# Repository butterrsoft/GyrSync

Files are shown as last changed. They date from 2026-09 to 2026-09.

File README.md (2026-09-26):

# 📺 GyrSync 

Gyr5

CRT TV/monitor protection and diagnostic dongle for 240p/15kHz, 25kHz and/or 480p/31kHz. With EDID, h-pos, v-pos, field-offset, and selectable sync pass/combine/polarity methods. Takes VGA/RGBHV input. Outputs C-sync on VGA pin 13 (or separate sync, if desired) when safe. Otherwise the Red led comes on and sync output is blocked. RGB still passes through, which is harmless on screen.

Powered via your VGA port, or any USB-C cable. Updates/reprograms via a single Gitbash Make command through an $8USD UPDI friend.

Gyrsync_x2

## Primary features
* Monitor sync protection at 15kHz and/or 25kHz and/or 31kHz.
* Vsync works at 45-65Hz input. But also when not present, so you can work only with H-sync if desired.
* Great for proving you're outputting the right video mode - comes in handy during system setup!
* VGA (TTL) RGBHV input only (Windows, Linux, MiSTer, HDMI-to-VGA) via DB15 3-row male plug, output via female socket.
* EDID can be turned on/off, and adjusted for H-size and H-pos. Or reprogrammed completely.
* H-pos, V-pos and field-offset direct adjustment.
* C-sync output with or without serration, separate H- and V-sync, sync polarity pass/flip.
* Three user profiles can hold different settings. 
* Lockout mode swallows stray button presses.
* Headless UI operation possible, for the most part.
* Diagnostic tools beyond the simple pass/fail sync rate indication, which itself is nothing to sneeze at!

Plan+test

### Read me first
Use a single power source wherever possible - try your VGA port first. If neither LED lights up, use a USB-C cable. *Don't* try to power other devices from the USB-C port on the Gyrsync. The Gyrsync has protection, but if something shorts you don't want to hurt anything.

There is one 1.27mm jumper inside the Gyrsync - allowing UPDI programming via VGA Pin 11 on the female VGA output side. This pin is no longer used by any display, but many/most cables tie it to ground. Leave the jumper off during normal use or the dongle mightn't boot if left in your setup (both red and green LED's will light dimly).

### Acknowledgments/Confessions:
I wanted to update Gambaman’s game-changing [Ultimate VGA to Scart Adapter](https://hackaday.io/project/165634-the-ultimate-vga-to-scart-adapter) and got carried away. Code by Claude, and, yes, I am embarrassed by that. All free and open-source, but who doesn't like seeing their name in print? 😆

## UI Navigation
UI is one button and one LED. Single button-presses change basic modes and adjust settings. Button-holds are timed to move between secondary modes, activating on release. Set the dongle as you want, then lock it so you can’t bump anything.

Dongle starts at Factory Reset – Mode 1, Profile 1, button locked out, Csync output, EDID off, all adjustments at default.

[Introduction and UI Navigation video](https://www.youtube.com/watch?v=2u9bSRtD6DU) Use the timestamps in the video if you need to. Keep the flowcharts below handy during use and remember that when holding the button down to move through the UI, the LED always gives some indication as you move to the next step.

UI full topology:
flowchart_Zeb_grey

UI simple topology:
```text
Lockout ──▶ Factory Reset
   │
   ▼
Modes 1-5 ──▶ Profile 1/2/3 ──▶ Mode S ──▶ Mode CS ──▶ Mode ED ──▶ Lockout ──▶ Factory Reset
                                    │
                                    ▼
                                 Mode H ──▶ Mode V ──▶ Mode FO
```

### Lockout Mode UI tables:
| Short press | No change |
|:---|:---|
| UI LED | Blinks mode, profile number |

| Hold, release | 3s | 10s |
|:---|:---|:---|
| UI LED | Blinking | Dark |
| Goes to | Mode 1-5, lockout removed | Factory reset |

### Mode 1-5 UI tables:
| Short press | Changes mode |
|:---|:---|
| UI LED | Blinks new mode, profile number |

| Hold, release | 2s | 4s | 6s | 8s | 11s | 13s | 16s | 25s |
|:---|:---|:---|:---|:---|:---|:---|:---|:---|
| UI LED | 1 blnk | 2 blnks | 3 blnks | 2+2 blnks | Solid | Dark | Blinking | Dark |
| Goes to | Profile 1 | Profile 2 | Profile 3 | Mode S | Mode CS | Mode ED | Lockout (at current settings) | Factory reset |

### Mode S UI tables:
| Short press | Goes to Mode 1 |
|:---|:---|
| UI LED | Blinks Mode 1, profile number |

| Double press | Toggle EDID on/off |
|:---|:---|
| UI LED | Accel./decel. pulses, respectively |

| Hold, release | 2s | 4s | 6s |
|:---|:---|:---|:---|
| UI LED | Solid | Dark | Blinking |
| Goes to | Mode H | Mode V | Mode FO |

### Adjustment Mode UI tables:
| Mode | H, V | ED, FO | CS |
|:---|:---|:---|:---|
| Short press | Step adj. | Step adj. | Sync pass/combine to next method |
| UI LED | Long blink middle and ends of adj. range only | Blink rate slower in middle, faster at ends. Long blink middle and ends. | Pulses method number |

| Hold | 2s | 4s | 6s | 8s (Mode ED only) |
|:---|:---|:---|:---|:---|
| UI LED | Solid | Dark | Solid | Pulsing |
| Action on release | Change adj. direction | Save adj. | Reset to default | Switch between pos/width (ED only) |

## Mode descriptions
Mode 1-5, Mode S information table:
| Mode |🔸Mode 1 | 🔸Mode 2 | 🔸Mode 3 | 🔸Mode 4 | 🔸Mode 5 | 🔸Mode S |
|:---|:---|:---|:---|:---|:---|:---|
| Passes | 15kHz | 31kHz | 15/31kHz | 25kHz | 15/25/31kHz | 15kHz + |
| EDID name | Mode1 - 15kHz | Mode 2 - 31kHz | Mode 3 - dualsyn | Mode 4 - 25kHz | Mode 5 - Trisync | Mode S - special |
| DTD 1 | 640x240p | 640x480p | 640x240p | 496x384p | 1280x240p | 640x240p |
| DTD 2 | 1280x240p | — | 1280x240p | — | 496x384p | 1280x240p |
| DTD 3 | 720x480i | — | 720x480i | — | 720x480i | 720x480i |

* DTD’s are timings/resolutions reported to Windows/Linux if you turn EDID on. Plug and play, baby! (In theory, at least, because Windows can be finicky and I'm waiting for more results from my testers. My RTX 5070, 980ti, old NV Quadro, and Radeon 5450's worked for 640x240p by simply plugging in the GyrSync after turning on EDID. My R7 360's do not.)
* Windows gets shitty about delivering interlaced video at low res in almost all cases.
* If your video mode pushes right up to the edges of any acceptable sync range, pass/fail detection is inconsistent and the output, along with your picture, will not be usable. Back off and move your modeline a notch or two inside the safe zone.
* Vsync (FPS) must be 45-65Hz, or absent entirely, or all output is blocked!

### 🔸 Mode S - special
Mode S passes 15kHz as normal, but takes 31kHz and halves it to make it 15kHz also - side-by-side images but at true 15kHz. This lets you use Safe Mode, or get out of trouble if Windows keeps grabbing 480p and pissing you off.

If there is no user activity, Mode S diagnoses sync status each 5s (but still blocks sync out of range). Will tell you if your cable is broken or wrong, or just that your system has gone to sleep.

Mode S sync report table:
| UI LED | 1 blink | 2 blinks | 3 blinks | Does nothing |
|:---|:---|:---|:---|:---|
| Means | No V-sync | No H-sync | No sync (both) | Sync ok |

### Adjustment modes
Adjustments are possible without a picture – power the dongle from any USB-C cable. The UI blinks SOS/cannot-adjust in only three scenarios: Mode FO if no interlaced mode is detected (progressive, or just missing vsync), Mode ED if EDID is off, Mode V if the source FPS is unstable. It is easiest to watch the screen while making most adjustments.

Adj. modes fall back to the mode you came from after 20s inactivity, or 30s for Mode ED. Same happens on reboot. Unsaved changes are discarded. After the long-blink at the end of an adjustment range, further presses move back in the other direction. The LED also long blinks at the default position.

Adj. mode h-sync pass table: (Prev. mode = if you were in Mode 4, 25kHz, then Mode ED is still at 25kHz.)
| Mode | Mode CS | Mode ED | Mode H | Mode V | Mode FO |
|:---|:---|:---|:---|:---|:---|
| Passes | Per prev. mode | Per prev. mode | 15/25/31kHz | 15/25/31kHz | 15/25/31kHz |

🔸 **Mode CS** - sync output method table: (On female DB15 output. Flip refers to the input sync polarity. Sync must be in range, still)
| Method | Mthd1 (default) | Mthd2 | Mthd3 | Mthd4 | Mthd5 | Mthd6 | Mthd7 |
|:---|:---|:---|:---|:---|:---|:---|:---|
| Pin13 (H-/C-sync)| Csync | Csync | Csync (no serr.) | pass | flip | pass | flip |
| Pin14 (V-sync)| block | pass | pass | pass | pass | flip | flip |

🔸 **Mode ED** - moves the h-pos and h-size in the EDID. Control defaults to h-pos/left, and when you hold for 8s goes to h-width/narrower. Changes affect *all* DTD’s over the current profile, across all modes. Different profiles can have different Mode ED settings. Changes do not show on the CRT as you make them - you must hit “Detect” under Windows Display Settings to see any changes, or, better, hot plug the dongle while USB-powered.

🔸 **Mode H** - moves h-pos. May *shimmy* very slightly, as the AVR32EB14 is only granular to 50ns. If you can, adjust the source, the CRT, or use Mode ED.

🔸 **Mode V** - moves v-pos.
 
🔸 **Mode FO** - field-offset! Interlaced only. Moves the odd field up and down vs the even field, to adjust flicker. I really wanted to try this, and it works, though YMMV.

## EDID
Extended Display Identification Data. Your OS reads it from any monitor and then sends the video timing mode the monitor asked for. The GyrSync transmits 15kHz, 25kHz and 31kHz timings based on how you set it. Modern OS’s are finicky, won’t do interlaced, but *should* grab the base 240p mode from the 15kHz timings and simply display it. Or 384p/480p depending on what you set. Wait for the green LED on the Gyrsync before plugging in your CRT.

**Troubleshooting EDID**
* [Go into Mode S](https://www.youtube.com/watch?v=2u9bSRtD6DU&t=462s) and [turn on EDID](https://www.youtube.com/watch?v=2u9bSRtD6DU&t=543s)
* Windows Display Settings > Advanced Display Settings for Desktop Resolution vs Active Signal Resolution. [Turn off scaling in your GPU settings](https://www.youtube.com/watch?v=IokpZT4ZYq4)
* Some older GPU's, OSes, or HDMI-to-VGA adapters may need a monitor plugged in, but not necessarily turned on, for the GyrSync to be detected. 
* Some HDMI-to-VGA dongles may mux-in EDID, which is ok, or simply provide their own, which is not.
* The EDID's allow audio over HDMI - change sound output in Windows if you need to.
* Something like crt_emudriver, CRU, or setting a cmdline.txt EDID in Linux, can override any physical EDID, and you won't see the GyrSync or it’s modelines listed anywhere. (Sync-protection and other features will still work as normal)

HDMI-to-VGA adapters can be great, but most cheap ones are now complete shit. At time of writing, [this cheap one](https://www.aliexpress.com/item/32976152001.html?spm=a2g0o.order_list.order_list_main.30.49cd1802Jc2KAH) works with the GyrSync, and probably with 240p in general :) (You need the flat cable version with audio). To use this particular converter you need a monitor plugged in, as above.

## Reprogramming:
The GyrSync targets an AVR32EB14, and is intended to be a simple as possible to reprogram. On Windows it needs [ZakKemble's latest AVR build](https://github.com/ZakKemble/avr-gcc-build) along with the install exe's, not zips, for [Git](https://git-scm.com/install/windows) and [Make](https://gnuwin32.sourceforge.net/packages/make.htm). Install git and make, then copy `make.exe`, `libintl3.dll` and `libiconv2.dll` into C:\Program Files\Git\usr\bin (or wherever you installed) or set your paths.

Programming is via UPDI 3-wire serial protocol. Unplug from your GPU or VGA source. Get a low-voltage UPDI friend/clone from aliexpress. Or even cheaper a USB-to-serial adapter set up as this:

UPDI

On the Gyrsync, stick pins into the VGA female end – pin 9 is 5V, pin 6, 7 or 8 for GND, and pin 11 for UPDI. Remember the 1.27mm UPDI jumper, or bridge the pins in a reversible fashion. Then open a gitbash (in any right-click context-menu) where you have the project files and type `make clean` then `make TOOLDIR="C:/path/to/avr-gcc-16.1.0-x64-windows/bin/" AVRDUDE="C:/path/to/avr-gcc-16.1.0-x64-windows/bin/avrdude.exe" flash PORT=COM6` remembering to check those paths and com port.

Most USB-to-serial adapters should work, like a CP2102, or even those CH341 eeprom programmers like below (just flip the jumper to TTL and use the pins as marked on the reverse). I did have trouble with a CH340-based cable though.

CH341

I wish i could have used USB or something, but the price and size goes up, and microcrontrollers with CCL and/xor gates don't use USB :/

### Editing EDID files (for programming)
Edit the project EDID files using a free program like Deltacast, or substitute your own EDID's, but keep the project filenames. The build needs all 6 EDID files named the same as the originals, at either 128 or 256 bytes. The intent is to allow you to adjust the picture a bit or add your own DTD timings, monitor names, etc. There is no protection from bad EDID files in the code, though it will still allow/block sync ranges as normal. If you do not add a CEA extension block or pad the EDID, the code will add an extension block making HDMI audio possible. If you get into trouble, restore the original EDID's.

Linux needs separate EDID's as it interprets the interlaced descriptor differently. 480i on Windows = 240i@60Hz, on Linux = 480i@30Hz. If you don't use interlaced modes you won't notice.

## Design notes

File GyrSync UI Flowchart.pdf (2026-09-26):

Red LED lit means no valid sync present, or another issue. Nothing passed. Green LED lit means valid sync present and video being passed
Blue LED blinks to indicate status, as detailed below
Time in seconds(s) refer to button press-hold time required; # = number in context

STATUS (report): # long blinks = MODE #, then # short blinks = PROFILE # (e.g. 1 long blink +2 short = Mode 1, PROFILE 2) ▲
│
│<3s | 10s
LOCKOUT | ───▶ RESET dark
│ | (Factory settings)
│3s
▼
MODE | 2s | 1 blink | 8s | 2+2 blinks | 11s solid | 13s dark
SELECT | ───▶ PROFILE #1 ───▶ MODE S | ───────────▶ | MODE CS
* | ───────▶ MODE ED

*
│ | │ | │ | (sync) | │ | (EDID adjust)
│ | │4s | 2 blinks | | │<2s | Reports | 16s blinking
│ | ───▶ PROFILE #2 | │ | STATUS | ───────▶ LOCKOUT
│ | │ | ─────▶ | sets MODE 1 | │ | (saves settings)
│ | │6s | 3 blinks | | │ | | 25s dark
│ | ───▶ PROFILE #3 | │<2s x 2 | Accelerating pulses = on | ───────▶ RESET
│ | │ | Decelerating pulses = off | (Factory settings)
│ | | | | ─────▶ | EDID ON / OFF
│ | | | | │ | (toggle)
│ | | | | │2s
│ | | | | ─────▶ | MODE H
*
(H-pos adjust)
│ | | | | │
│<2s | | | | │4s
▼ | | | | ─────▶ | MODE V

*
(V-pos adjust)
MODE +1, modes cycle 1-5, then | │
Reports STATUS (see above) | │6s
Refer Mode Descriptions below | ─────▶ | MODE FO*
(Field Offset)

* Refer Adjustment Mode UI Tables below for more information
Please watch videos: GyrSync - 15kHz/31kHz CRT protection dongle - Introduction & UI overview (https://www.youtube.com/watch?v=2u9bSRtD6DU) GyrSync - Win 10 EDID process - Active Signal Resolution vs Desktop Resolution. (https://www.youtube.com/watch?v=IokpZT4ZYq4)

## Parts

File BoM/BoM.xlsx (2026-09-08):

Qty | Part | Package | Desc.
1 | AVR32EB14 | SOIC | Main IC
1 | USB-C 6-pin | - | USB type-C female socket
1 | ECS-3961-200-AU-TR | 5032 | Oscillator
2 | SDB13HS-AQ | SOD323 | Schottky Diode
1 | PESD5V0U1BAF | SOD323 | TVS Diode
1 | LED 3mm Gr | 3mm TH | Green through-hoole 3mm LED
1 | LED 3mm Re | 3mm TH | Red through-hoole 3mm LED
1 | LED 3mm Bu | 3mm TH | Blue through-hoole 3mm LED
1 | TS02-66-90-BK-160-LCR-D | 6x6x9mm TH | Tactile switch - any with same dimensions ok
1 | SMD Cap 22uF or higher | 1206 | bulk cap, at least 15V
1 | SMD Cap 100nf | 0603 | filter cap
4 | SMD 1k resistor | 0603 | LED's can use higher values if desired
2 | SMD resistor 5k1 | 603 | for USB PD 5V supply
1 | 1.27mm 2-pin header | - | for programming
1 | 1.27mm 2-pin jumper | - | for programming
1 | VGA Male - straight pins | DB15 M 3-row | NOT solder-type
1 | VGA Female - straight pins | DB15 M 3-row | NOT solder-type
2 | Threaded insert | 4-40x3/16x4.6 | optional - for clamping to female VGA
2 | hex standoff | 4-40x L 5mm, 6mm | optional - for clamping to female VGA
2 | 4/40 9mm jack screw | 4-40 x 3/8 | optional - for clamping to male VGA

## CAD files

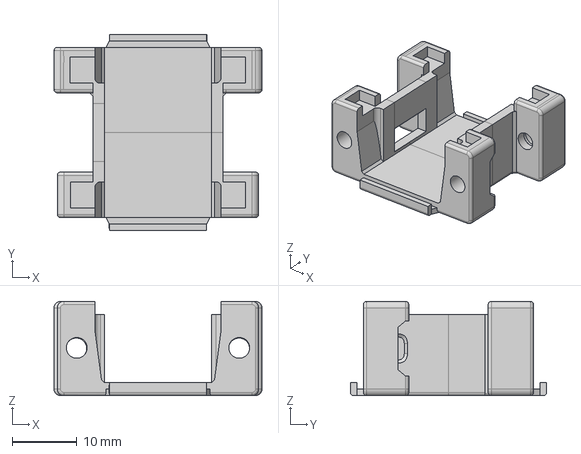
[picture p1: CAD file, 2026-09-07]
Case/GyrSync_body.step
32.0 x 30.2 x 14.5 mm

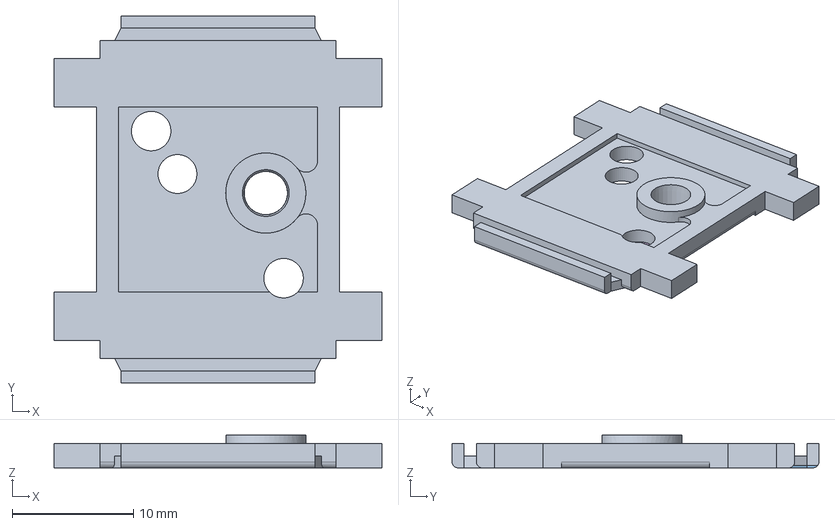
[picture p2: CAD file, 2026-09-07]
Case/GyrSync_lid_TH-bird.step
27.0 x 30.2 x 2.70 mm

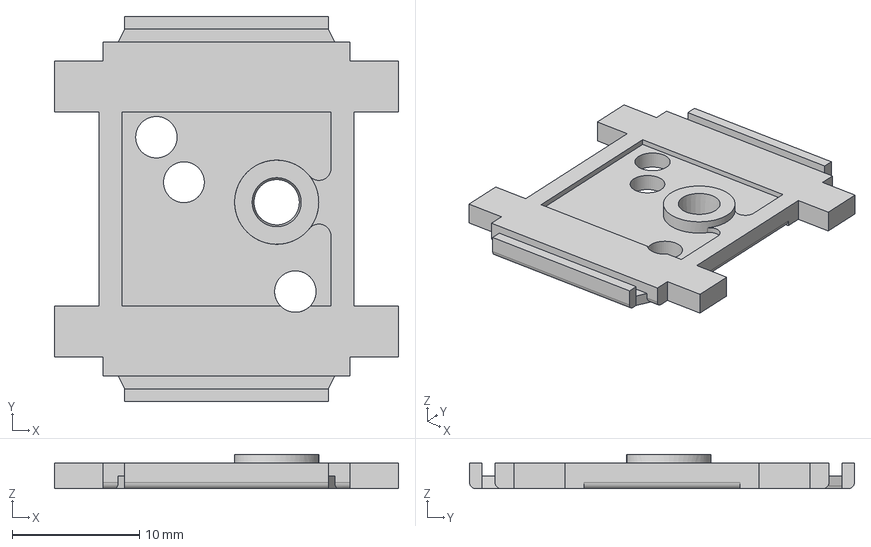
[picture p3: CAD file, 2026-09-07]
Case/GyrSync_lid_TH-plain.step
27.0 x 30.2 x 2.70 mm

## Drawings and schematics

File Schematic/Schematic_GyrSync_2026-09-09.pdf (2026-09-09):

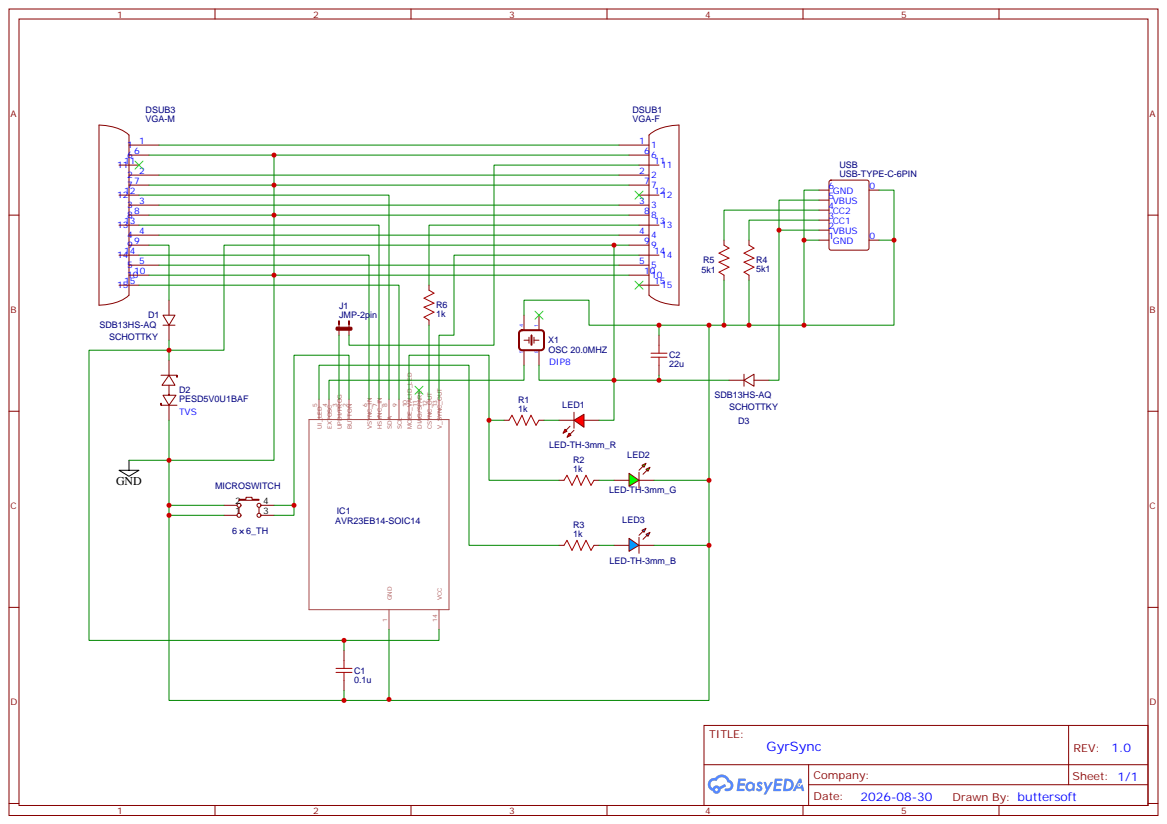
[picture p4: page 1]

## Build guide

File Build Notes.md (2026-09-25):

## CAUTION
This build is a bitch. My OCD/aesthetic requires i design things to be as small as possible, sorry. I will probably update with a second, larger, through-hole PCB, or one that can be assembled for you by a fab, but this is it for now...

Order PCB at 1.0mm thick (or less, and edit the case body step file). Make sure you get VGA plugs/sockets with straight, thin pins. NOT solder pins with the cup-shape. Hard to find, but required here.

If you don't build in the following order, you will run into problems. Get some kapton tape. Go slowly. Check continuity to make sure you haven't shorted anything at each step. Work out *why* you are trimming each leg or VGA pin before doing so. Measure twice, cut once.

## Solder components in this order:
1. Both Schottky diodes
2. Resistor for Green LED
3. Oscillator
4. Tactile switch (trim legs before soldering so they don't poke through at all, then insulate the pad closest to the top middle with kapton tape, so the USB-C socket doesn't short it to ground)
5. All other SMD components on the top side but NOT the 5k1 resistors
6. USB-C (make sure not to ground the switch!)
7. 5k1 resistors
8. All SMD components on the lower side, but not the AVR23EB14 main IC
9. Male/female DB15 3-row plug/socket (making sure to trim pins as below)
10. RGB wires (I like 28AWG solid-core high-temp wire for this). Connect pin1 to pin1, pin2 to pin2, pin3 to pin3.
11. 1.27mm 2-pin header
12. Blue LED (you will probably want to insulate the legs so the Red wire doesn't short to them, can use 1.5/3mm heatshrink)
13. Green LED (trim the legs before soldering so the AVR23EB14 can still sit flush)
14. AVR32EB14!
15. Red LED

## Trim VGA pins so:

### Male DB15 3-row

| Pin | Length (after trimming) |
| --- | --- |
| 1 | 3mm or bend out |
| 2 | 1.8mm |
| 3 | 1.8 |
| 4 | remove/trim flush |
| 5 | remove/trim flush |
| 6 | 1.8 |
| 7 | 1.8 |
| 8 | 1.8 |
| 9 | 1.8 |
| 10 | 2.2 |
| 11 | remove/trim flush |
| 12 | 1.8 |
| 13 | 1.8 |
| 14 | 1.8 |
| 15 | 2.2 |

### Female DB15 3-row

| Pin | Length (after trimming) |
| --- | --- |
| 1 | 3mm or bend out |
| 2 | 1.8mm |
| 3 | 1.8 |
| 4 | remove/trim flush |
| 5 | remove/trim flush |
| 6 | 1.8 |
| 7 | 1.8 |
| 8 | 1.8 |
| 9 | 1.8 |
| 10 | remove/trim flush |
| 11 | 1.8 |
| 12 | remove/trim flush |
| 13 | 2.2 |
| 14 | 2.2 |
| 15 | remove/trim flush |

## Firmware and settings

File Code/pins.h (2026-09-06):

#ifndef CSYNC_PINS_H
#define CSYNC_PINS_H

/* ===================================================================
 * Pin map -- AVR32EB14, SOIC14. THE AUTHORITATIVE COPY.
 * ===================================================================
 *
 * This replaces the map in main.c's header comment, which had drifted:
 * it still described pin 11 as the interlace indicator long after the
 * default became fo_active (spec v2 open item 5). One copy cannot
 * disagree with itself.
 *
 * THERE IS ONE MAP. Rev 1 -- the pre-rotation wiring, DDC on pins 4/5
 * and Csync on pin 9 -- was deleted once this map had had a full
 * regression pass on the bench. `BOARD_REV` is gone with it; a build
 * that passes -DBOARD_REV=1 now fails rather than silently producing
 * this map.
 *
 * | Pin | Port | Owner            | Function                          |
 * |-----|------|------------------|-----------------------------------|
 * |  1  | GND  | --               | --                                |
 * |  2  | PF6  | ui               | B1, active low, internal pull-up  |
 * |  3  | PF7  | --               | UPDI -- NEVER REPURPOSE           |
 * |  4  | PA0  | clock            | EXTCLK in -- GND until fitted     |
 * |  5  | PA1  | ui               | Blink LED                         |
 * |  6  | PC0  | evsys/ccl        | Vsync in -- PULLUPEN + BOTHEDGES  |
 * |  7  | PC1  | evsys/ccl        | Hsync in, TCB0 capture            |
 * |  8  | PC2  | ddc              | SDA (TWI0 client, PORTMUX ALT2)   |
 * |  9  | PC3  | ddc              | SCL                               |
 * | 10  | PD4  | video            | Mode-Valid LED                    |
 * | 11  | PD5  | --               | spare, driven low by port_init()  |
 * | 12  | PD6  | ccl              | Csync out <- LUT2 OUT, always     |
 * | 13  | PD7  | modev            | regenerated Vsync (Mode CS's V)   |
 * | 14  | VDD  | --               | --                                |
 *
 * PIN 6 IS WRITTEN ONCE, and that is load-bearing rather than tidy.
 * PULLUPEN and ISC share PINnCTRL, so a second plain write to arm the
 * edge interrupt takes the pull-up off -- which is what it did, and
 * what made the Mode-Valid LED tick with the Vsync lead off. See
 * port_init().
 *
 * PIN 12 IS THE ONE THAT HAS ACTUALLY GONE WRONG, twice -- both times
 * under the old pinout, where pin 12 was the regenerated Vsync. An
 * interlace indicator was left on it when Mode V took it, so
 * v_line_tick() raised the regenerated pulse and the stale indicator
 * flattened it microseconds later. A diagnostic then gave the same pin
 * to a LUT as a scope output, which overrides PORT silently -- a second
 * writer would not show as a conflict, it would show as the pulse
 * twitching low for a few hundred nanoseconds a frame, which is the
 * size of the thing being measured.
 *
 * So pin 12's ownership is asserted here rather than remembered. Every
 * claimant defines its symbol; claiming it twice fails the build. */

/* THIS HEADER DECIDES who owns pin 12, and that is the enforcement --
 * not an #error. An #error comparing two claims cannot help when both
 * are derived from the same switch, and preprocessor conditions cannot
 * see across translation units anyway. What is available is removing
 * the second opinion.
 *
 * Pin 12 is Csync, permanently, and Mode V is on pin 13. Nothing is
 * borrowed and nothing stands down. The three symbols that used to say
 * so -- PIN12_OWNER_CCL, PIN12_OWNER_MODEV and MODEV_YIELDS_PIN -- had
 * become constants with one reachable value, which is a false signal:
 * the next reader of `#if MODEV_YIELDS_PIN` would believe the pin was
 * still negotiated. They are gone, and so is the dead branch in main.c
 * that tested one of them. */

/* BOARD_REV IS GONE. It selected between this wiring and the one
 * before the rotation, and the old one has been deleted -- so a stale
 * command line carrying -DBOARD_REV=1 would otherwise build THIS map
 * while the person at the bench probed for the other one. Fail
 * instead. Delete this guard once no command line, script or note
 * anywhere still names it. */
#ifdef BOARD_REV
#error "BOARD_REV no longer exists -- rev 1 was deleted. Drop it from the command line."
#endif

/* GATE_VIA_PIN IS GONE TOO, for the same reason and in the same shape:
 * it drove pin 10, pin 10 is the Mode-Valid LED, so the option could
 * not be built. Guarded rather than silently ignored. */
#ifdef GATE_VIA_PIN
#error "GATE_VIA_PIN no longer exists -- pin 10 is the Mode-Valid LED. Drop it from the command line."
#endif
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

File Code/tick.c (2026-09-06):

/* TCF0 -- the 1kHz housekeeping timebase. SINGLE OWNER OF TCF0.
 *
 * Nothing outside this file names TCF0. That is the point of the
 * split: the register set and the one variable derived from it are
 * reachable only through now_ticks() and elapsed_since().
 *
 * TCF0 has no alternative PORTMUX routing, so WO0EN/WO1EN staying
 * clear is the only thing keeping it off PORTA -- the DDC lines. That
 * constraint now lives in one file with the register writes it
 * constrains, rather than in a comment several thousand lines away. */

#include "tick.h"

#include <avr/io.h>
#include <avr/interrupt.h>

/* ===================================================================
 * Housekeeping timebase
 * ===================================================================
 *
 * TCF0 in frequency-generation mode. It overflows at 4kHz and the
 * millisecond tick is a division of that -- see the note below the
 * constants. Ticks are counted in software.
 *
 * Section 12 of the spec asks for a TCB here, to avoid both the TCF
 * read erratum and the RTC's loose internal oscillator. Both TCBs are
 * spoken for -- TCB0 measures Hsync, TCB1 carries the one-shots from
 * increment 3 -- so this is the arrangement that satisfies what that
 * asked for rather than how it asked for it. The erratum is that
 * TCF0.CNT may return a wrong value because its high bytes can change
 * after the low bytes are read; counting overflow INTERRUPTS never
 * reads CNT at all, so it cannot bite. And the tick rides the 20MHz
 * clock, so unlike the RTC nothing needs rescaling against a measured
 * oscillator.
 *
 * A 1kHz interrupt against a 15-31kHz sync signal is not a hazard: the
 * sync path is entirely combinational logic in the CCL, so no interrupt
 * latency anywhere in this firmware can glitch the output.
 *
 * 1ms ticks in a uint16_t wrap every 65.536s -- longer than any
 * interval this design measures, the 25s factory-reset hold included,
 * so the usual wraparound-safe subtraction covers everything.
 *
 * qtick_count counts the same overflows undivided, so 250us a count and
 * a 16.384s wrap. Only the field-rate check reads it and the only
 * interval it measures is a single field, so the shorter wrap costs it
 * nothing. See tick.h for why no accessor is offered.
 */
#define TICK_HZ            1000UL

/* TCF0 NOW OVERFLOWS AT 4kHz, NOT 1kHz, AND THE MILLISECOND TICK IS A
 * DIVISION OF IT.
 *
 * The Blink LED has no hardware PWM available to it. TCF0's own
 * outputs reach only PA0/PA1 and stay disabled for it (see tcf0_init);
 * both TCBs are committed, TCB0 to the Hsync capture and TCB1 to the
 * three one-shot jobs; and TCE0's period IS the line, so its output
 * would stop whenever the source did -- which is precisely when the
 * indicator matters most. Software PWM therefore needs a periodic
 * interrupt, and this is the only one in the design that is both
 * regular and unrelated to the sync signal.
 *
 * 4kHz with a 16-level PWM frame gives 250Hz, comfortably above flicker
 * fusion, and divides EXACTLY by four back to the 1kHz tick: 20MHz /
 * 4000 = 5000 with no remainder, and 4000 / 1000 = 4. tick_count
 * therefore counts the same milliseconds it always did, and every hold,
 * strobe and timeout in the UI is unaffected. The asserts below are
 * what keep that true if either rate is ever edited. */
#define PWM_HZ             4000UL
#define TCF_CMP_FOR_PWM    ((F_CPU / PWM_HZ) - 1)    /* 4999 */
#define PWM_PER_TICK       ((uint8_t)(PWM_HZ / TICK_HZ))

_Static_assert(TCF_CMP_FOR_PWM < 0x1000000UL, "TCF CMP exceeds 24 bits");
_Static_assert(F_CPU % PWM_HZ == 0,  "PWM_HZ must divide F_CPU exactly");
_Static_assert(PWM_HZ % TICK_HZ == 0, "PWM_HZ must be a whole multiple of TICK_HZ");

volatile uint16_t tick_count;
volatile uint16_t qtick_count;

/* EXPORTED DELIBERATELY, AND ONLY FOR LEVEL-0 INTERRUPT CONTEXT.
 *
 * now_ticks() double-reads because the main loop can be interrupted
 * between the two bytes. An ISR at level 0 cannot be interrupted by
 * TCF0, which is also level 0, so the plain read is safe there and
 * the double-read would be waste in a path that matters. The Vsync
 * ISR takes the frame interval this way.
 *
 * Declared in tick.h with this condition stated, so a future caller
 * at level 1 or in the main loop has to read the condition before it
 * can reach the variable. */

/* Ordinary priority. The TCB0 capture holds level 1 (see main(), where
 * CPUINT.LVL1VEC is written), so it preempts this ISR properly -- better
 * than the ISR_NOBLOCK this used to carry, because NOBLOCK only
 * re-enables interrupts after the prologue has already run, and it opens
 * the question of an ISR re-entering itself. Level 1 preemption is
 * immediate and has neither drawback.
 *
 * That promotion was described here and in the capture's own comment for
 * some time before it was actually written to LVL1VEC. It is written
 * now. If the capture is ever demoted, both comments and the frame-
 * boundary hand-off through v_frame_req have to move with it. */
ISR(TCF0_INT_vect)
{
    TCF0.INTFLAGS = TCF_OVF_bm;

    /* Every overflow: one PWM sub-tick. Lives in main.c, which owns the
     * Blink LED pin; this file owns TCF0 and nothing else. Passing the
     * work out through a call rather than reaching for the pin here is
     * what keeps both statements true -- LTO inlines it back in, so the
     * split costs nothing at run time. */
    tick_pwm_service();

    /* Every overflow: one quarter-millisecond. Incremented here rather
     * than derived from tick_count and subdiv, because a reader would
     * then have to sample two variables the ISR updates separately and
     * could land between them. One counter, one store. */
    qtick_count++;

    /* Every fourth: one millisecond. */
    static uint8_t subdiv;
    if (++subdiv < PWM_PER_TICK) return;
    subdiv = 0;

    tick_count++;
}
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
